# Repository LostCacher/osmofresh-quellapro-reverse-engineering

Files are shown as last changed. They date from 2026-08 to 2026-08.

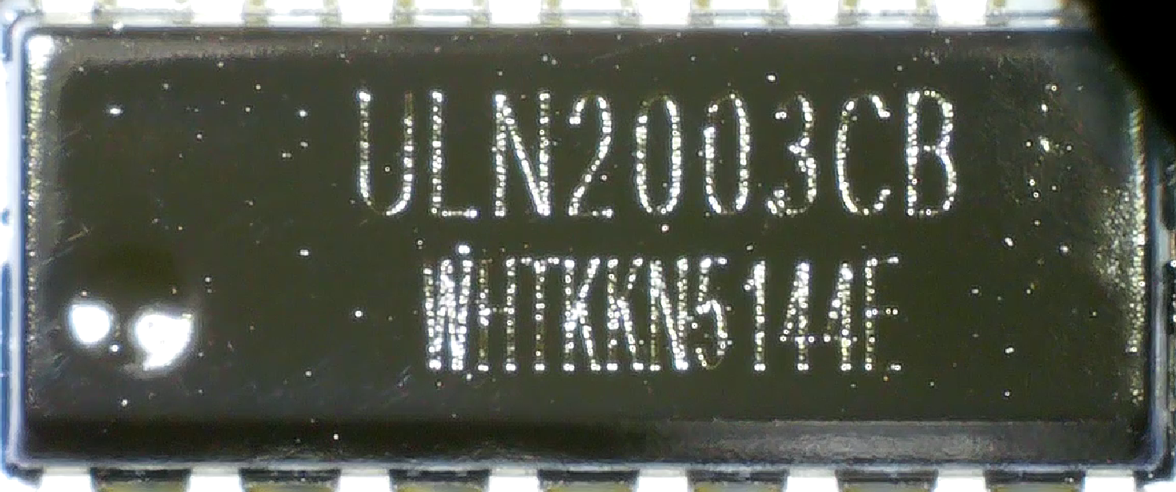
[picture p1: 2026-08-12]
Pictures/Display_U1.png

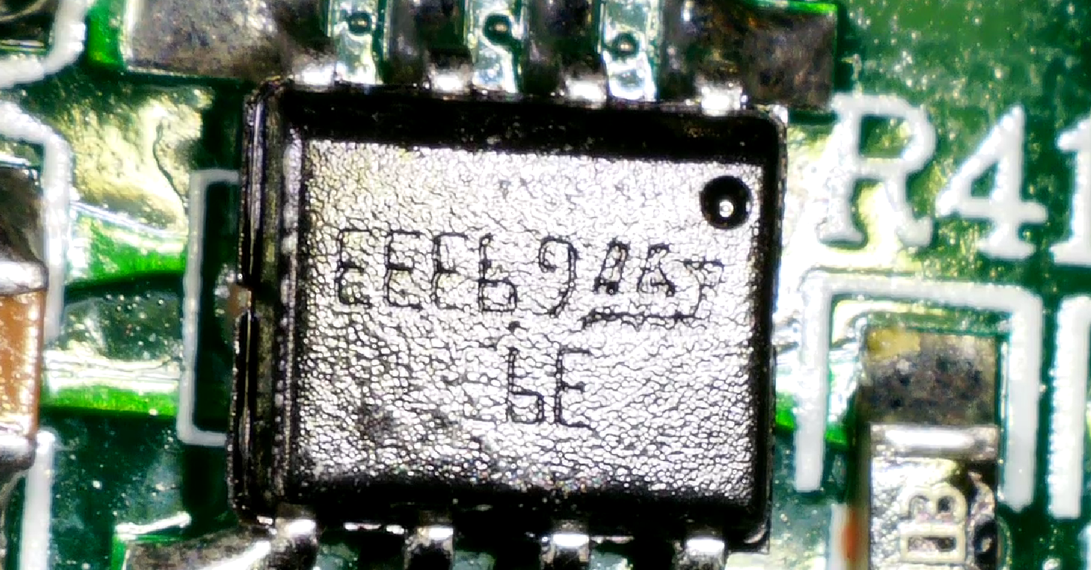
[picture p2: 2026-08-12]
Pictures/Hauptplatine_U5_8Pin.png

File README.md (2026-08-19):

# OsmoFresh Quella Pro Reverse Engineering

> Reverse engineering and hardware documentation of the OsmoFresh Quella Pro water dispenser.

## Project Goals

This project aims to document the hardware architecture of the OsmoFresh Quella Pro to improve repairability and technical understanding.

Current objectives include:

- Reverse engineering the hardware
- Creating complete schematics
- Identifying electronic components
- Documenting the UART communication protocol
- Documenting sensors and actuators
- Exploring the possibility of custom firmware (if technically feasible)

## Repository Structure

```
Hardware/
Documentation/
Photos/
Datasheets/
Measurements/
UART/
Firmware/
```

## Project Status

⚠️ This project is currently work in progress.
The published schematics are based on reverse engineering and may contain errors or incomplete sections.

- ✅ Device teardown
- ✅ Component identification
- ✅ Primary power stage schematic
- ✅ Main PCB reverse engineering
- 🔄 UART protocol analysis
- ⏳ Firmware investigation

## Contributions, corrections and additional information are welcome.

## Disclaimer

This repository contains independently created documentation based on reverse engineering.

No proprietary firmware, copyrighted schematics, confidential documentation, or other copyrighted material from the manufacturer is included.

All schematics, measurements, photographs, and documentation were created independently.

## License

This repository is licensed under the MIT License.

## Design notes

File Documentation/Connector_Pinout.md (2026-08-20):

# Connector Pinout

## Primary Side (230 VAC)

| Connector | Description |
|---|---|
| **P1** | ACL → Heater |
| **P2** | ACN → Thermal safety switch → Heater |
| **P3** | ACN → AC mains input |
| **P4** | ACN → 24 VDC power supply |
| **P5** | ACL → 24 VDC power supply |
| **P6** | ACL → AC mains input |

---

## Secondary Side (24 VDC)

| Connector | Description |
|---|---|
| **CN1** | 24 VDC input (from power supply) [+24Vdc] |
| **CN2** | Reed switch (2-pin) – Water tank empty detection |
| **CN3** | Water temperature sensor (heater outlet) [+5Vdc] |
| **CN5** | Water temperature sensor (heater inlet) [+5Vdc] |
| **CN6** | Reed switch (2-pin) – Internal tank level sensor (black HW or NW) |
| **CN7** | UNUSED |
| **CN8** | UNUSED [+5Vdc] |
| **CN9** | TDS sensor (2-pin) |
| **CN10** | 6-pin actuator connector |
| **CN11** | Display interface (5 V, TX, RX, GND) [+5Vdc] |
| **CN12** | Feed Pump [+24Vdc] |
| **CN13** | UNUSED [+24Vdc] |
| **CN14** | Reed switch (2-pin) – Internal tank level sensor (red HW or NW)|
| **CN16** | UNUSED [+5Vdc] |

### CN10 Pinout

| Pin | Function |
|----:|---|
| 1 | GND |
| 2 | +24 V (Not connected) [+24Vdc] |
| 3 | GND |
| 4 | +24 V Flush Valve [+24Vdc] |
| 5 | GND |
| 6 | +24 V Booster Pump [+24Vdc] |

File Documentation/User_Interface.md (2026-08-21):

# User Interface

## Temperature Selection

| Option | Description |
|---|---|
| RT | Room Temperature Water |
| 45 °C | Milk |
| 55 °C | Tea |
| 80 °C | Soup |
| 90 °C | Coffee |
| 100 °C | Boiling Water |

---

## Volume Selection

| Volume |
|---------|
| 150 mL |
| 300 mL |
| 450 mL |
| 600 mL |
| 750 mL |
| 900 mL |

---

## User Controls

- Temperature Selection
- Volume Selection
- Filter Change
- Power On / Off
- Child Lock

---

## Status Indicators

- Selected Volume
- TDS Value
- Water Temperature
- Water Tank Empty (Red Water Drop)
- Filter Process Active (White Water Drop)
- Internal Tank Empty (White Water Drop Flashing)
- Filter Lifetime (Stage 1 / 2 / 3)
- Malfunction + Error Code

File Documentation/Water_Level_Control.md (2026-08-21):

# Water Level Control

This document describes the water level monitoring and pump control logic of the internal and external water tanks.

---

# Sensors

## Internal Tank Level MIN

- Connector: CN14
- Reed switch: Normally Closed (NC)
- Trigger height: ~90 mm
- Function:
  - Indicates that the minimum required water level has been reached.
  - Enables the feed pump.
  - Does **not** start the feed pump automatically.

---

## Internal Tank Level MAX

- Connector: CN6
- Reed switch: Normally Closed (NC)
- Trigger height: ~180 mm
- Function:
  - Stops / inhibits the booster pump.

---

## External Water Tank Empty

- Connector: CN2
- Reed switch: Normally Open (NO)
- Function:
  - Detects an empty external water tank.
  - Stops / inhibits the booster pump.

---

# Booster Pump Logic

The booster pump is inhibited when:

- The external water tank is empty.
- The internal tank reaches the MAX level.

The booster pump is allowed to operate again when the corresponding inhibit condition is no longer present.

---

# Feed Pump Logic

The feed pump may only operate when:

- The Internal Tank Level MIN sensor has been reached (feed pump enabled).

The MIN sensor only provides the permission to operate the feed pump.
The feed pump starts only when requested by the control logic (e.g. during a dispensing cycle).

---

# Dispensing Logic

The controller keeps track of the **cumulative dispensing time**.

After approximately **25 seconds of total water dispensing**, the booster pump is enabled again to refill the internal tank.

The dispensing time is accumulated across multiple dispensing cycles and is not reset when dispensing is interrupted.

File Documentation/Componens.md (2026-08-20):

# MainPCB Bill of Materials (BOM)

This document lists all components identified on the OsmoFresh Quella Pro MainPCB.

> **Status**
> - ✅ = Identified
> - 🟡 = Partially identified
> - ❓ = Unknown / To be analyzed

---

# Protection Devices

| RefDes | Component | Value | Model | Status |
|---|---|---|---|:---:|
| FUSE1 | Fuse | T16A | TT16AL250V | ✅ |
| ZNR1 | Varistor | 560 V | VDR 14D561K | ✅ |

---

# Integrated Circuits (IC)

| RefDes | Component | Value / Function | Part Number / Marking | Package | Status | Notes |
|---|---|---|---|---|:---:|---|
| IC1 | MCU | Main Controller | HIGHWAY-C225F | QFP-28 | ✅ | Custom MCU |
| U1 | Buck Converter | 24 V → 5 V DC/DC | Unknown | SOT-23-5 | 🟡 | Step-down converter |
| U3 | Zero-Cross Triac Driver Optocoupler | MOC3063M | SOIC-6 | ✅ | Optically isolated zero-cross triac driver |
| U4 | Darlington Driver | 7-Channel Driver | ULN2003A | SOIC-16 | ✅ | Low-side driver array |
| U5 | Dual Comparator | Voltage Comparator | KM393 | SOIC-8 | ✅ | Dual comparator |

---

# Relays

| RefDes | Function | Model | Coil Voltage | Contact Rating | Status |
|---|---|---|---|---|:---:|
| K1 | Heater Relay | Vuanze Y32F-SS-124HM | 24 VDC | 10 A / 250 VAC | ✅ |
| K2 | Bosoter Pump Relay | Vuanze Y32F-SS-124DM | 24 VDC | 5 A / 250 VAC | ✅ |

---

# Mechanical Components

| RefDes | Description | Status | Notes |
|---|---|:---:|---|
| SW1 | Thermal Safety Switch | ✅ | Heater protection |

---

# Transformers / Magnetics

| RefDes | Component | Model | Status | Notes |
|---|---|---|:---:|---|
| T1 | Signal Transformer | JB-TV/A2/2-E | ✅ | AC sensing / Zero-cross detection |
| L1 | Inductor | Unknown | 🟡 | Parallel to buck inductor L1 |

---

# Transistors / Power Switches

| RefDes | Type | Part Number | Package | Status | Notes |
|---|---|---|---|:---:|---|
| Q1 | TRIAC | BTA16-800CW | TO-220 | ✅ | 900 W heater triac |
| Q2 | NMOS | Unknown | SOT-23 | 🟡 | Heater relay low-side driver |
| Q3 | NPN BJT | Unknown | SOT-23 | 🟡 | Input inverter / signal conditioning |
| Q4 | PMOS | Unknown | SOT-23 | 🟡 | Feed Pump high-side switch |
| Q5 | NPN BJT | Unknown | SOT-23 | 🟡 | Booster pump relay low-side driver |
| Q6 | NPN BJT | Unknown | SOT-23 | 🟡 | Input inverter / signal conditioning |
| Q8 | NPN BJT | Unknown | SOT-23 | 🟡 | PMOS gate driver |

---

# Diodes

| RefDes | Type | Model | Status | Notes |
|---|---|---|:---:|---|
| D4 | Flyback Diode | Unknown | 🟡 | K1 relay coil suppression |
| D5 | Flyback Diode | Unknown | 🟡 | Booster pump inductive load suppression |
| D6 | Flyback Diode | Unknown | 🟡 | Feed Pump inductive load suppression |
| D7 | Flyback Diode | Unknown | 🟡 | K2 relay coil suppression |

---

# Resistors

| RefDes | Value | Type | Package | Status | Notes |
|---|---|---|---|:---:|---|
| RL1 | Unknown | Resistor | SMD 1206 | 🟡 | Parallel to L1 (buck converter) |
| R4 | 2 kΩ | Resistor | SMD 0805 | ✅ | |
| R5 | 2 kΩ | Resistor | SMD 0805 | ✅ | |
| R6 | 10 kΩ | Resistor | SMD 0805 | ✅ | |
| R7 | 180 Ω | Resistor | SMD 2010 | ✅ | Triac gate resistor |
| R10 | 2 kΩ | Resistor | SMD 0805 | ✅ | |
| R11 | 10 kΩ | Resistor | SMD 0805 | ✅ | |
| R12 | 2 kΩ | Resistor | SMD 0805 | ✅ | |
| R13 | 2 kΩ | Resistor | SMD 0805 | ✅ | |
| R14 | 1 kΩ | Resistor | SMD 0805 | ✅ | |
| R15 | 10 kΩ | Resistor | SMD 0805 | ✅ | |
| R16 | 2 kΩ | Resistor | SMD 0805 | ✅ | |
| R17 | 2 kΩ | Resistor | SMD 0805 | ✅ | |
| R18 | 4.7 kΩ | Resistor | SMD 0805 | ✅ | |
| R19 | 470 Ω | Resistor | SMD 0805 | ✅ | |
| R20 | 10 kΩ | Resistor | SMD 0805 | ✅ | |
| R21 | 1 kΩ | Resistor | SMD 0805 | ✅ | |
| R22 | 2 kΩ | Resistor | SMD 0805 | ✅ | |
| R23 | 47 kΩ | Resistor | SMD 0805 | ✅ | |
| R24 | 2 kΩ | Resistor | SMD 0805 | ✅ | |
| R25 | 1 kΩ | Resistor | SMD 0805 | ✅ | |
| R26 | 82 kΩ | Resistor | SMD 1206 | ✅ | AC sense resistor chain |
| R27 | 82 kΩ | Resistor | SMD 1206 | ✅ | AC sense resistor chain |
| R28 | 82 kΩ | Resistor | SMD 1206 | ✅ | AC sense resistor chain |
| R29 | 10 kΩ | Resistor | SMD 0805 | ✅ | |
| R30 | 10 kΩ | Resistor | SMD 0805 | ✅ | |
| R31 | 4.7 kΩ | Resistor | SMD 0805 | ✅ | |
| R32 | 510 Ω | Resistor | SMD 0805 | ✅ | |
| R33 | 10 kΩ | Resistor | SMD 0805 | ✅ | |
| R34 | 510 Ω | Resistor | SMD 0805 | ✅ | |
| R35 | 10 kΩ | Resistor | SMD 0805 | ✅ | |
| R36 | 10 kΩ | Resistor | SMD 0805 | ✅ | |
| R37 | 10 kΩ | Resistor | SMD 0805 | ✅ | |
| R38 | 10 kΩ | Resistor | SMD 0805 | ✅ | |
| R40 | 10 kΩ | Resistor | SMD 0805 | ✅ | |
| R41 | 10 kΩ | Resistor | SMD 0805 | ✅ | |
| R44 | 330 Ω | Resistor | SMD 0805 | ✅ | |
| R45 | 2 kΩ | Resistor | SMD 0805 | ✅ | |
| R49 | 220 Ω | Resistor | SMD 0805 | ✅ | |
| R50 | 220 Ω | Resistor | SMD 0805 | ✅ | |
| R51 | 750 Ω | Resistor | SMD 1206 | ✅ | |
| R52 | 750 Ω | Resistor | SMD 1206 | ✅ | |
| R53 | 10 kΩ | Resistor | SMD 0805 | ✅ | |
| R54 | 10 kΩ | Resistor | SMD 0805 | ✅ | |
| R55 | 5.1 Ω | Power resistor | SMD 2010 | ✅ | Feed pump current shunt |
| R59 | 470 Ω | Resistor | SMD 0805 | ✅ | |
| R60 | 10 kΩ | Resistor | SMD 0805 | ✅ | |
| R61 | 47 kΩ | Resistor | SMD 0805 | ✅ | |
| R62 | 0.62 Ω | Power resistor | Axial THT | ✅ | Booster pump current shunt |
| R63 | 0.62 Ω | Power resistor | Axial THT | ✅ | Booster pump current shunt |
| R64 | 2 kΩ | Resistor | SMD 0805 | ✅ | |
| R65 | 2 kΩ | Resistor | SMD 0805 | ✅ | |
| R66 | 2 kΩ | Resistor | SMD 0805 | ✅ | |
| R67 | 10 kΩ | Resistor | SMD 0805 | ✅ | |
| R68 | 10 kΩ | Resistor | SMD 0805 | ✅ | |

---

# Capacitors

| RefDes | Value | Type | Package | Voltage | Status | Notes |
|---|---|---|---|---|:---:|---|
| XC1 | 100 nF | X2 Safety Capacitor | Radial Box THT (10 mm LP) | 275 VAC | ✅ | |
| EC1 | 470 µF | Electrolytic | Radial Electrolytic Ø12.5 × 20 mm | 50 V | ✅ | |
| EC2 | 330 µF | Electrolytic | Radial Electrolytic Ø6.3 × 11 mm oder Ø6.3 × 11.5 mm | 10 V | ✅ | |
| C1 | Unknown | Ceramic | 0805 | Unknown | 🟡 | |
| C2 | Unknown | Ceramic | 0805 | Unknown | 🟡 | |
| C3 | Unknown | Ceramic | 0805 | Unknown | 🟡 | |
| C4 | Unknown | Ceramic | 0805 | Unknown | 🟡 | |
| C5 | Unknown | Ceramic | 0805 | Unknown | 🟡 | |
| C6 | Unknown | Ceramic | 0805 | Unknown | 🟡 | |
| C7 | Unknown | Ceramic | 0805 | Unknown | 🟡 | |
| C8 | Unknown | Ceramic | 0805 | Unknown | 🟡 | |
| C9 | Unknown | Ceramic | 0805 | Unknown | 🟡 | |
| C10 | Unknown | Ceramic | 0805 | Unknown | 🟡 | |
| C11 | Unknown | Ceramic | 0805 | Unknown | 🟡 | |
| C12 | Unknown | Ceramic | 0805 | Unknown | 🟡 | |
| C13 | Unknown | Ceramic | 0805 | Unknown | 🟡 | |
| C14 | Unknown | Ceramic | 0805 | Unknown | 🟡 | |
| C15 | Unknown | Ceramic | 0805 | Unknown | 🟡 | |
| C16 | Unknown | Ceramic | 0805 | Unknown | 🟡 | |
| C17 | Unknown | Ceramic | 0805 | Unknown | 🟡 | |
| C18 | Unknown | Ceramic | 0805 | Unknown | 🟡 | |
| C19 | Unknown | Ceramic | 0805 | Unknown | 🟡 | |
| C20 | Unknown | Ceramic | 0805 | Unknown | 🟡 | |
| C21 | Unknown | Ceramic | 0805 | Unknown | 🟡 | |
| C22 | Unknown | Ceramic | 0805 | Unknown | 🟡 | |
| C23 | Unknown | Ceramic | 0805 | Unknown | 🟡 | |
| C24 | Unknown | Ceramic | 0805 | Unknown | 🟡 | |
| C25 | Unknown | Ceramic | 0805 | Unknown | 🟡 | |
| C26 | Unknown | Ceramic | 0805 | Unknown | 🟡 | |
| C27 | Unknown | Ceramic | 0805 | Unknown | 🟡 | |

---

# Notes

- Unknown components will be updated as reverse engineering progresses.
- Values are taken from PCB markings whenever possible.
- Package sizes are identified by physical measurements where no manufacturer data is available.
- Datasheets are available in the `Datasheets/` directory where applicable.

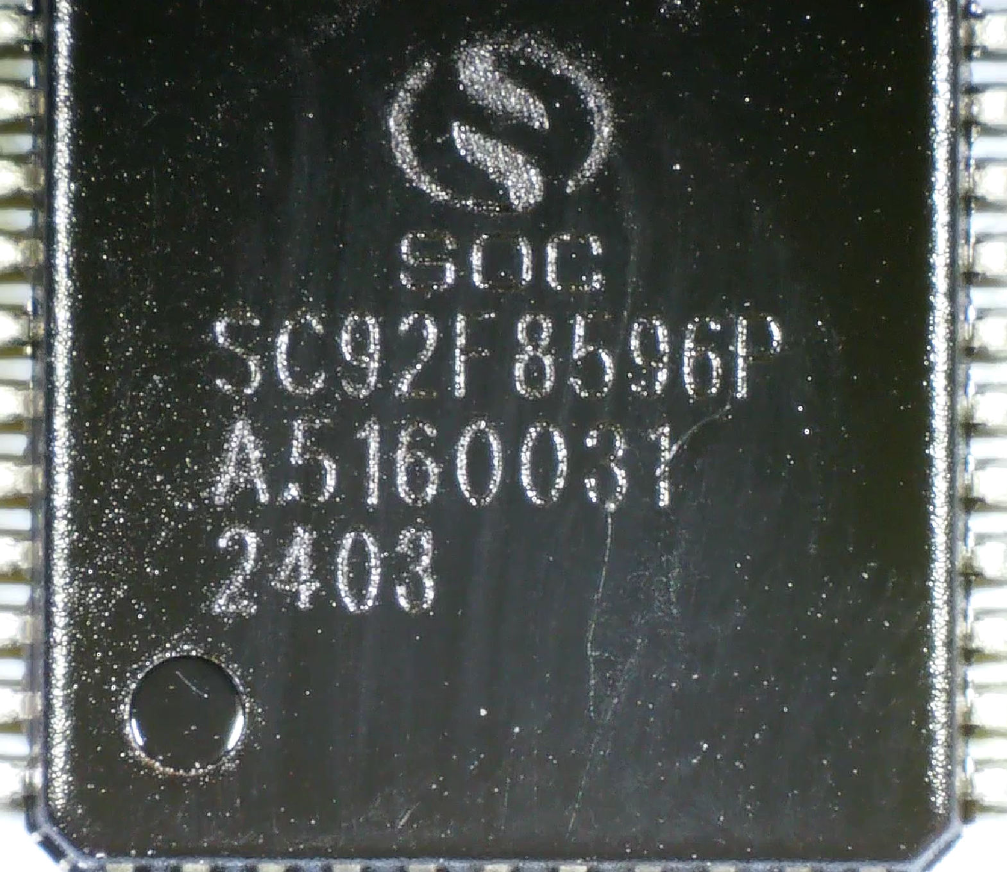
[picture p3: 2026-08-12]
Pictures/Display_U2.png

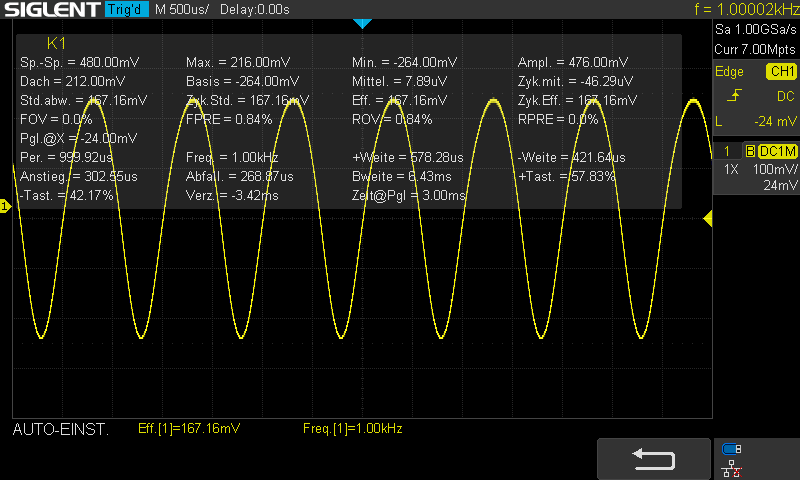
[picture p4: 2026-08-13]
Pictures/Transformer_Secondary.png

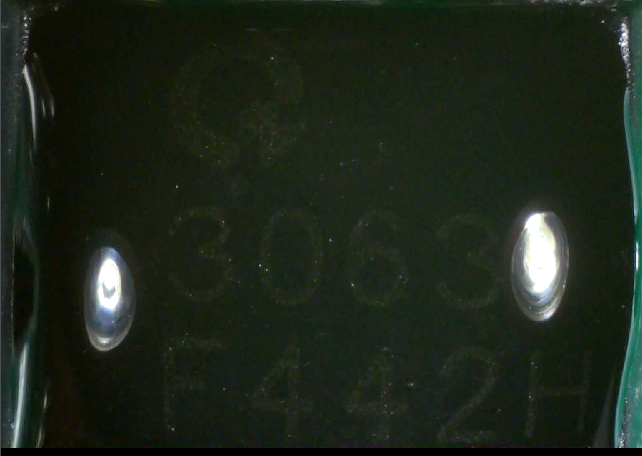
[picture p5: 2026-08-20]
Pictures/Hauptplatine_U3_6Pin.png

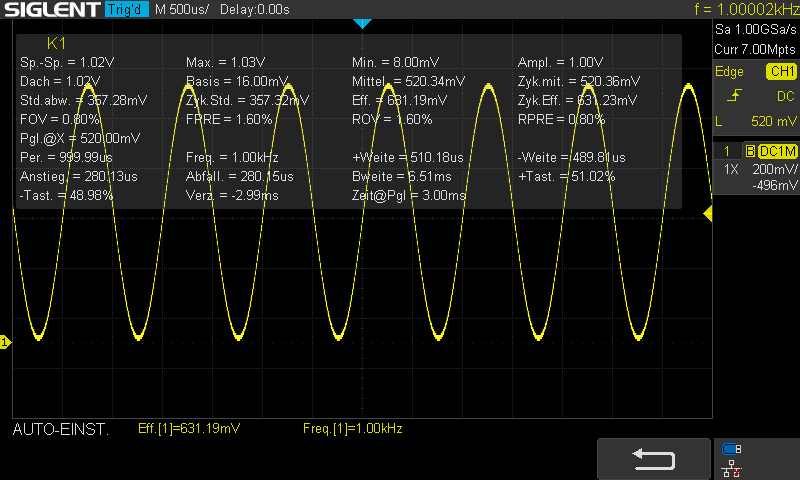
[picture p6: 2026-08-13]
Pictures/Transformer_Primary.png

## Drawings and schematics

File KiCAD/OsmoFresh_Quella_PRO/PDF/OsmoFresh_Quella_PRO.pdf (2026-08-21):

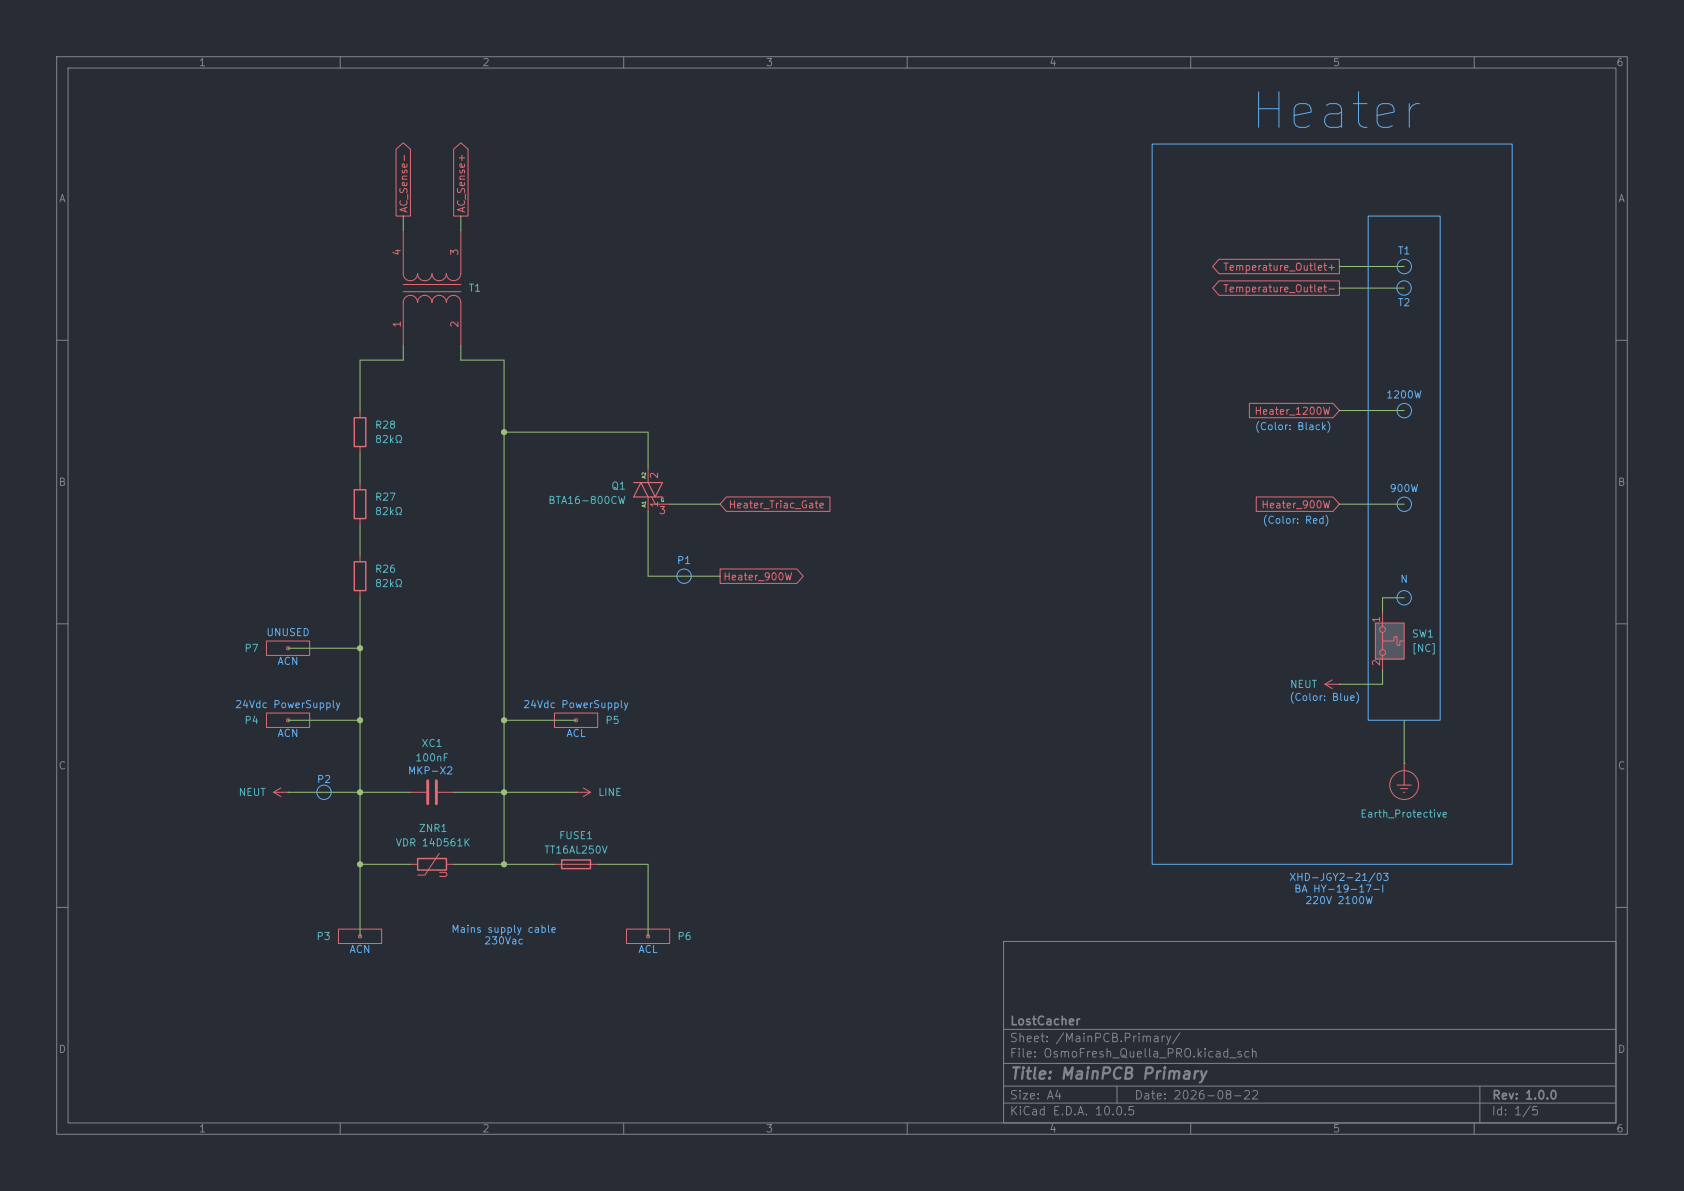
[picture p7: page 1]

P1 MKP-X2Mains supply cable 230Vac UNUSED

Size: A4 | Rev: 1.0.0
KiCad E.D.A. 10.0.5 | Id: 1/5

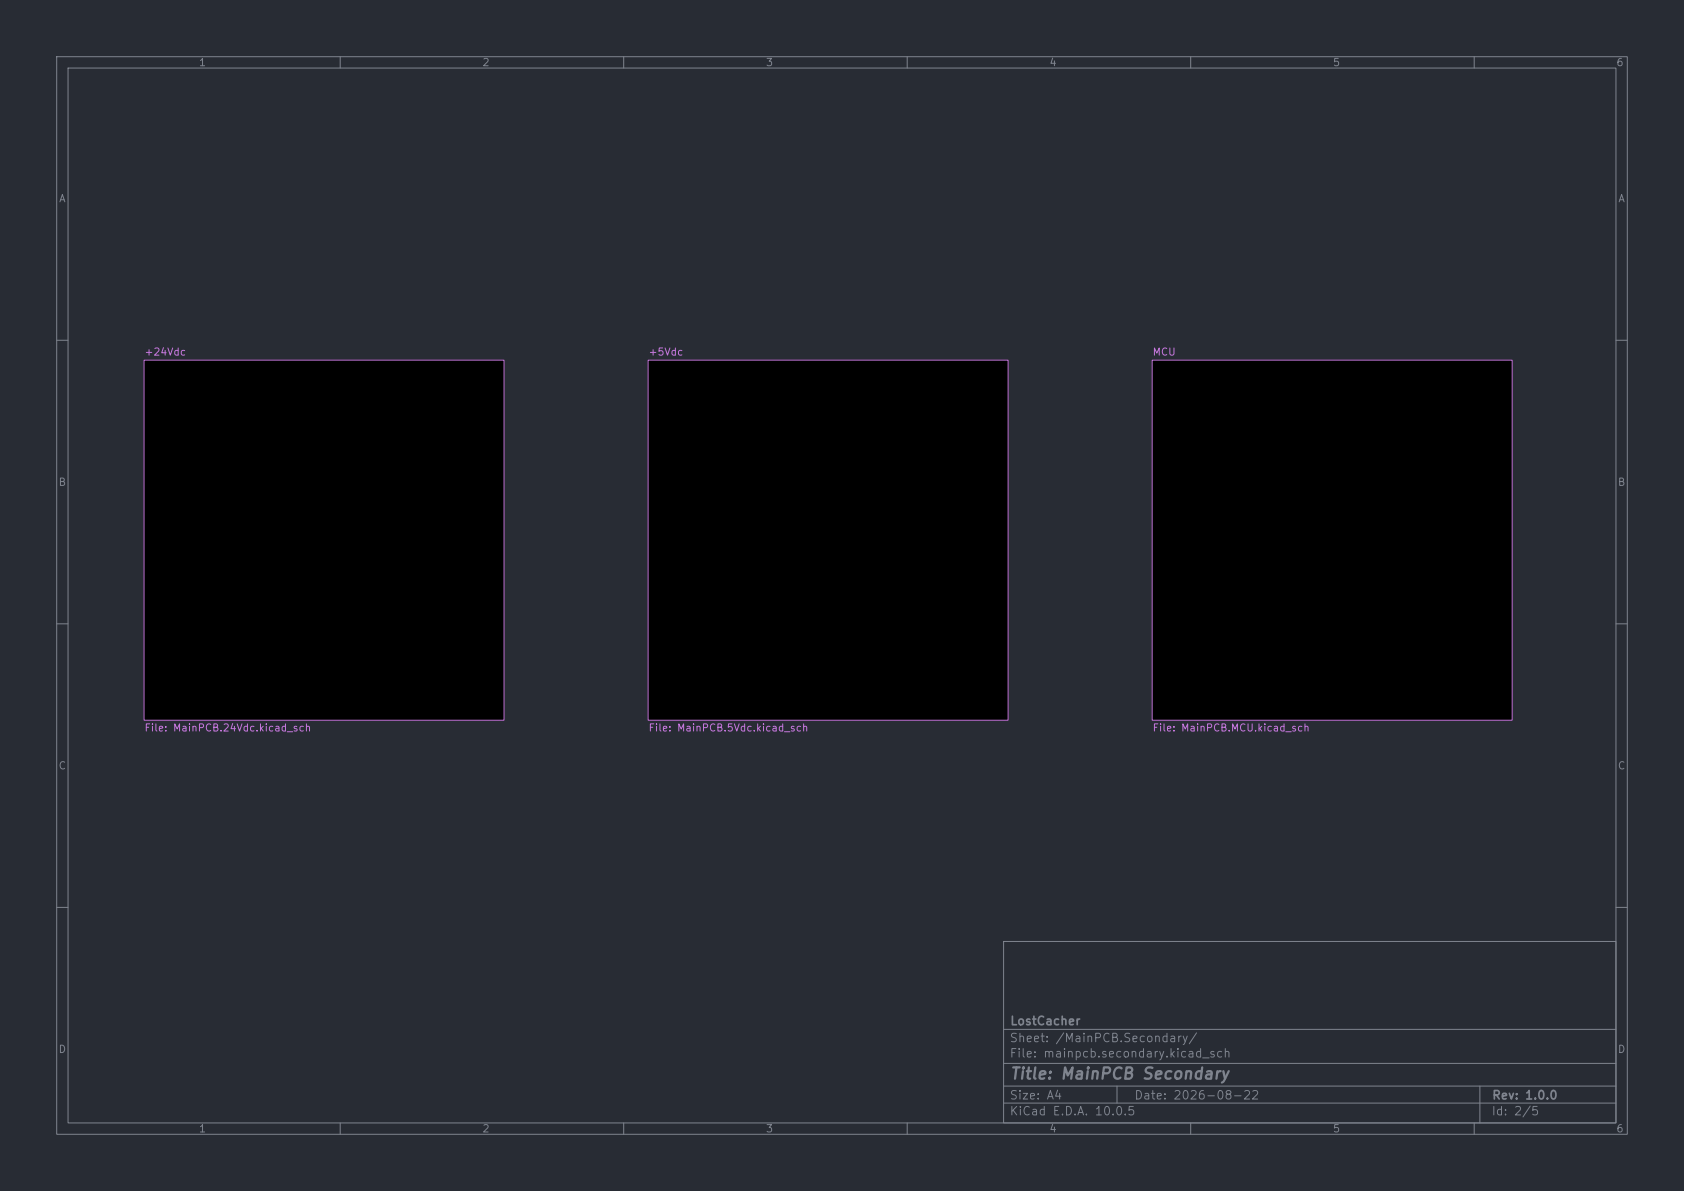
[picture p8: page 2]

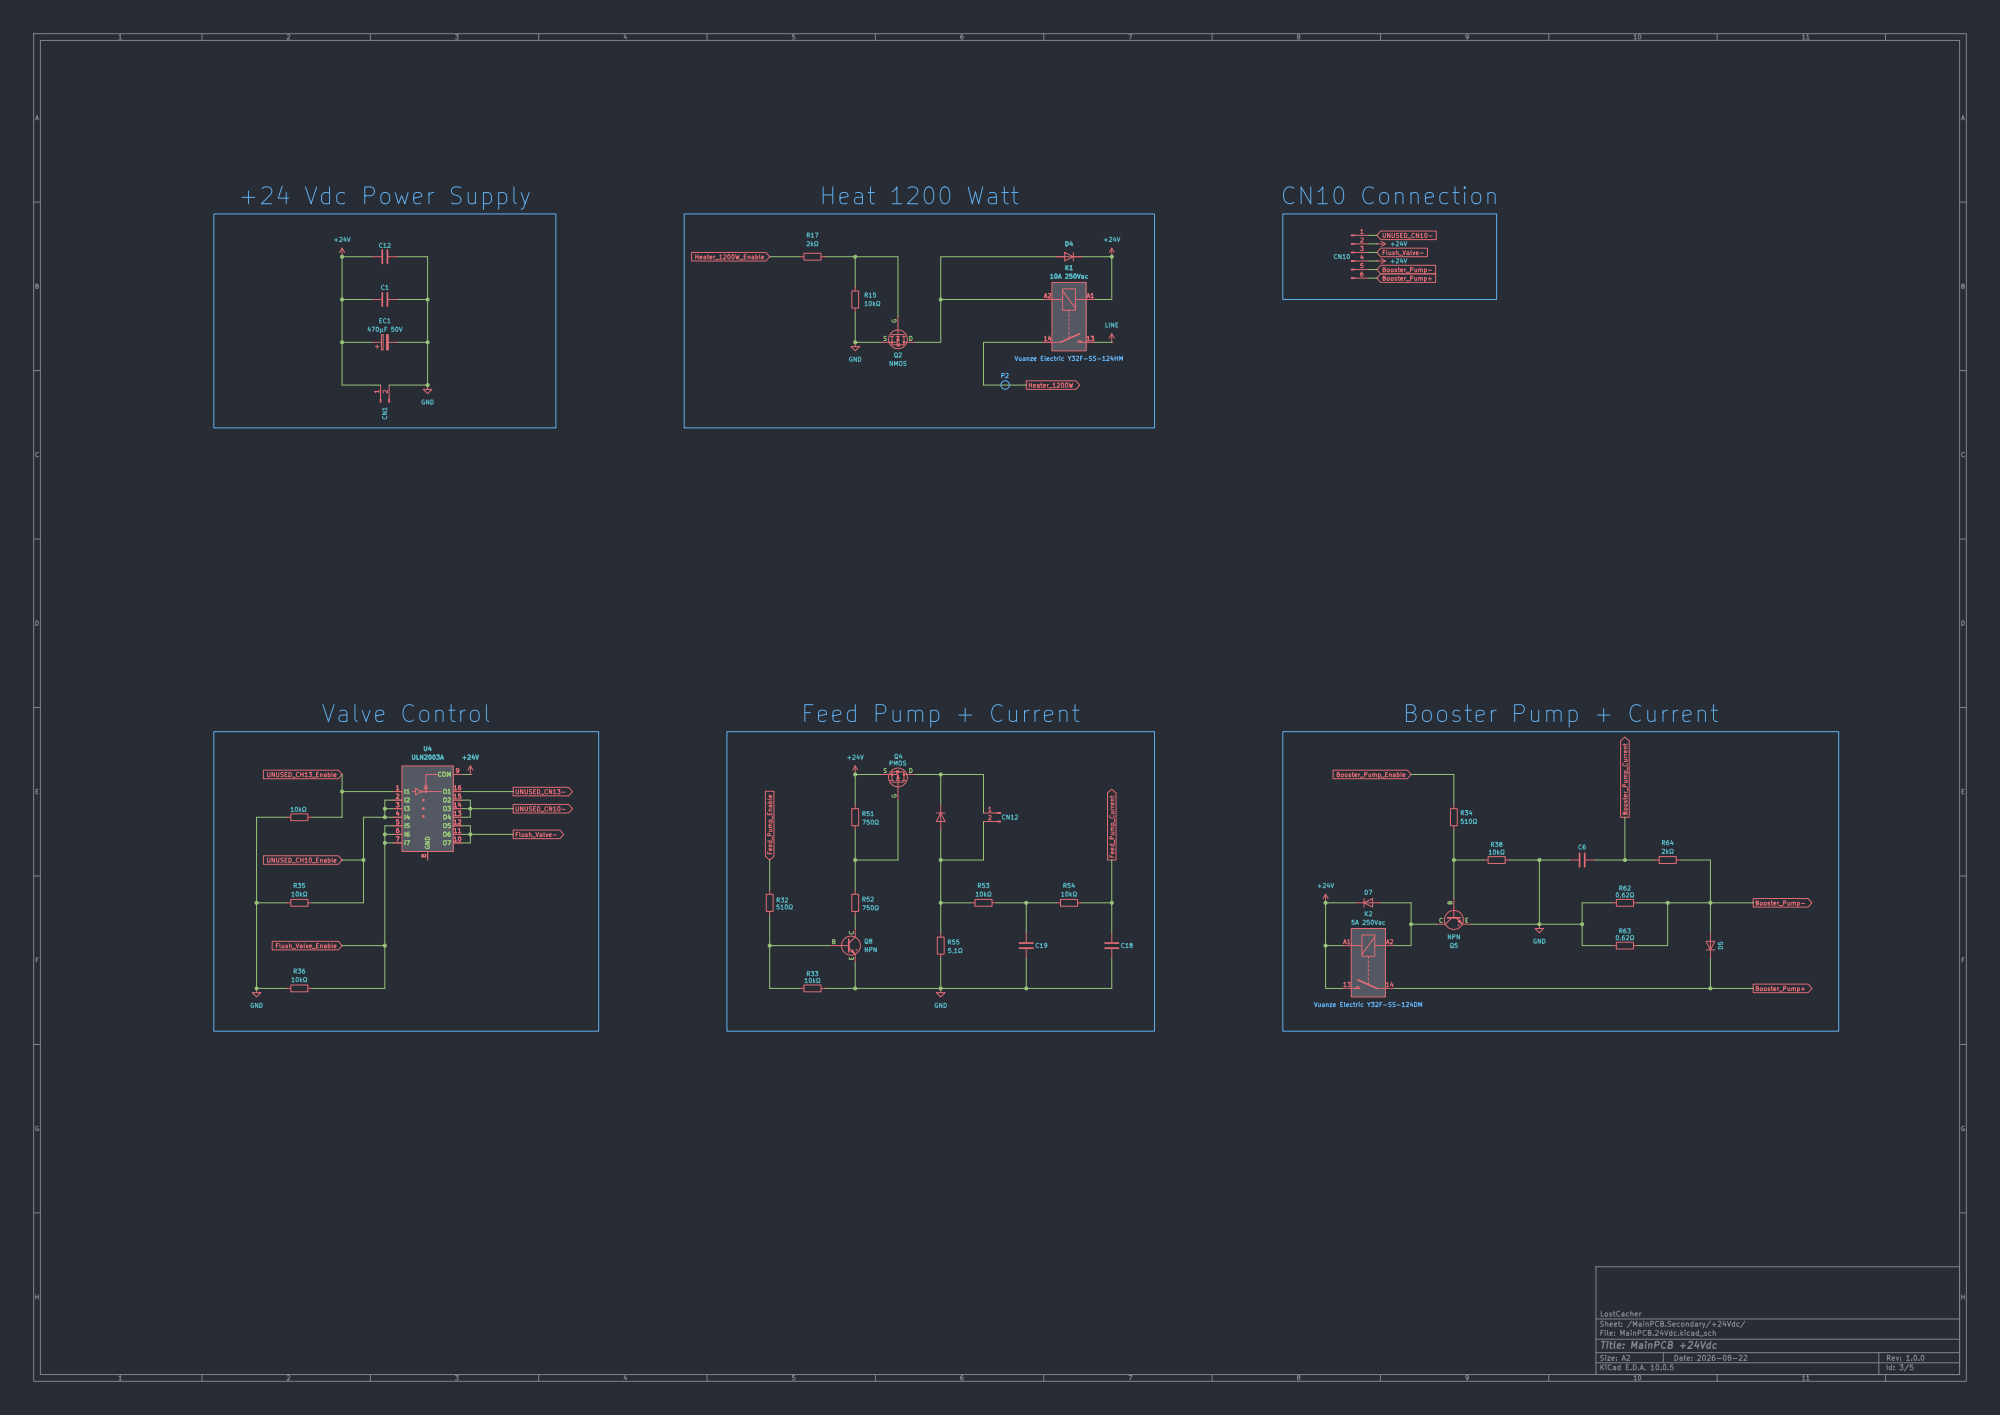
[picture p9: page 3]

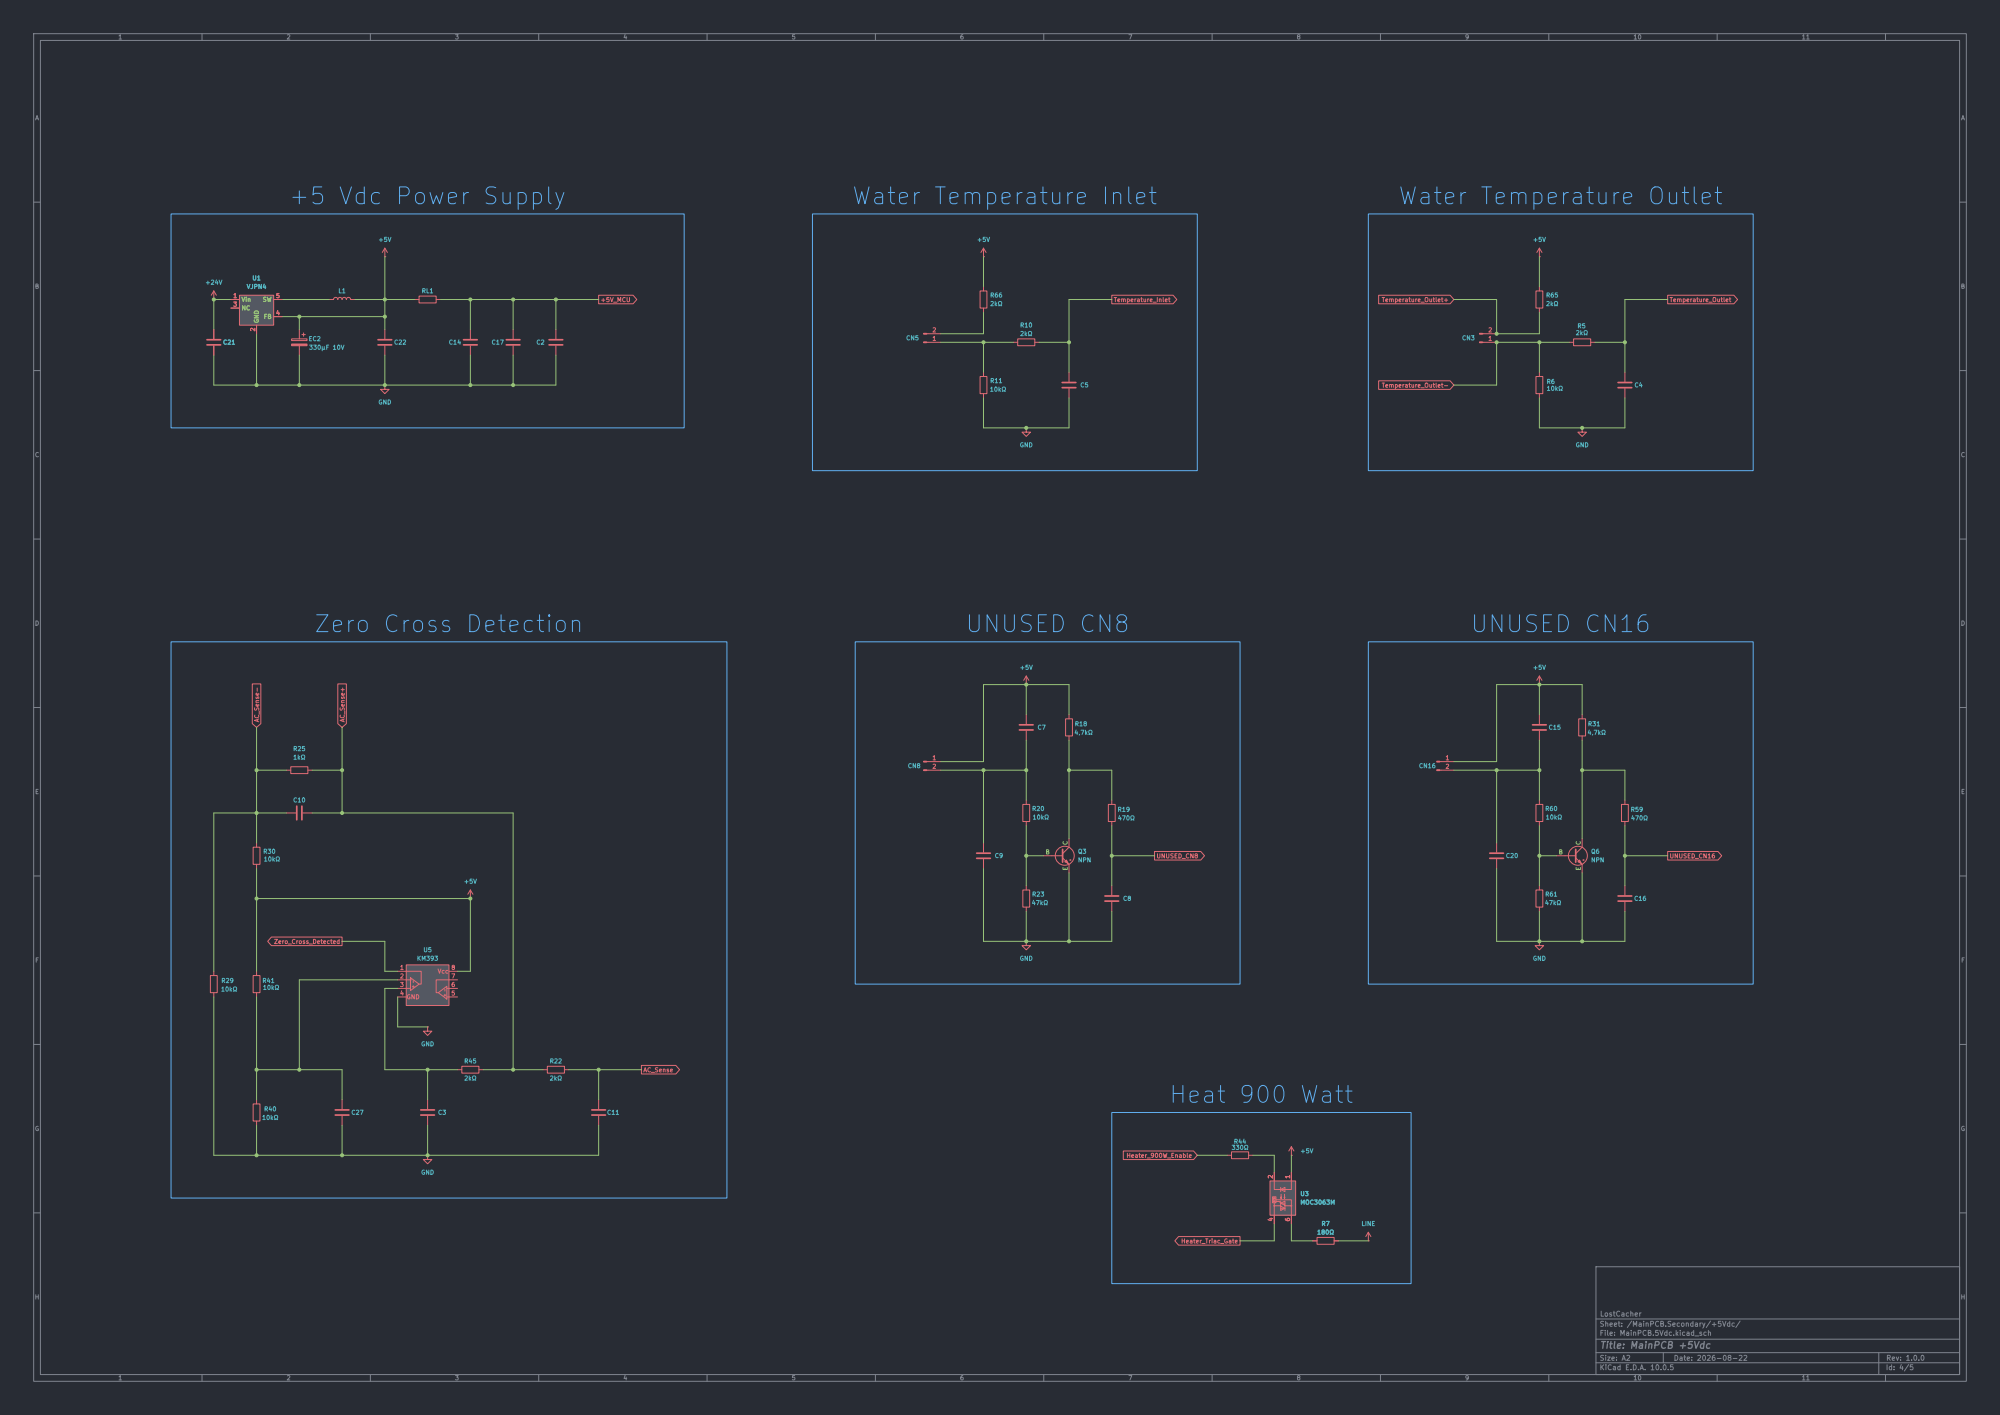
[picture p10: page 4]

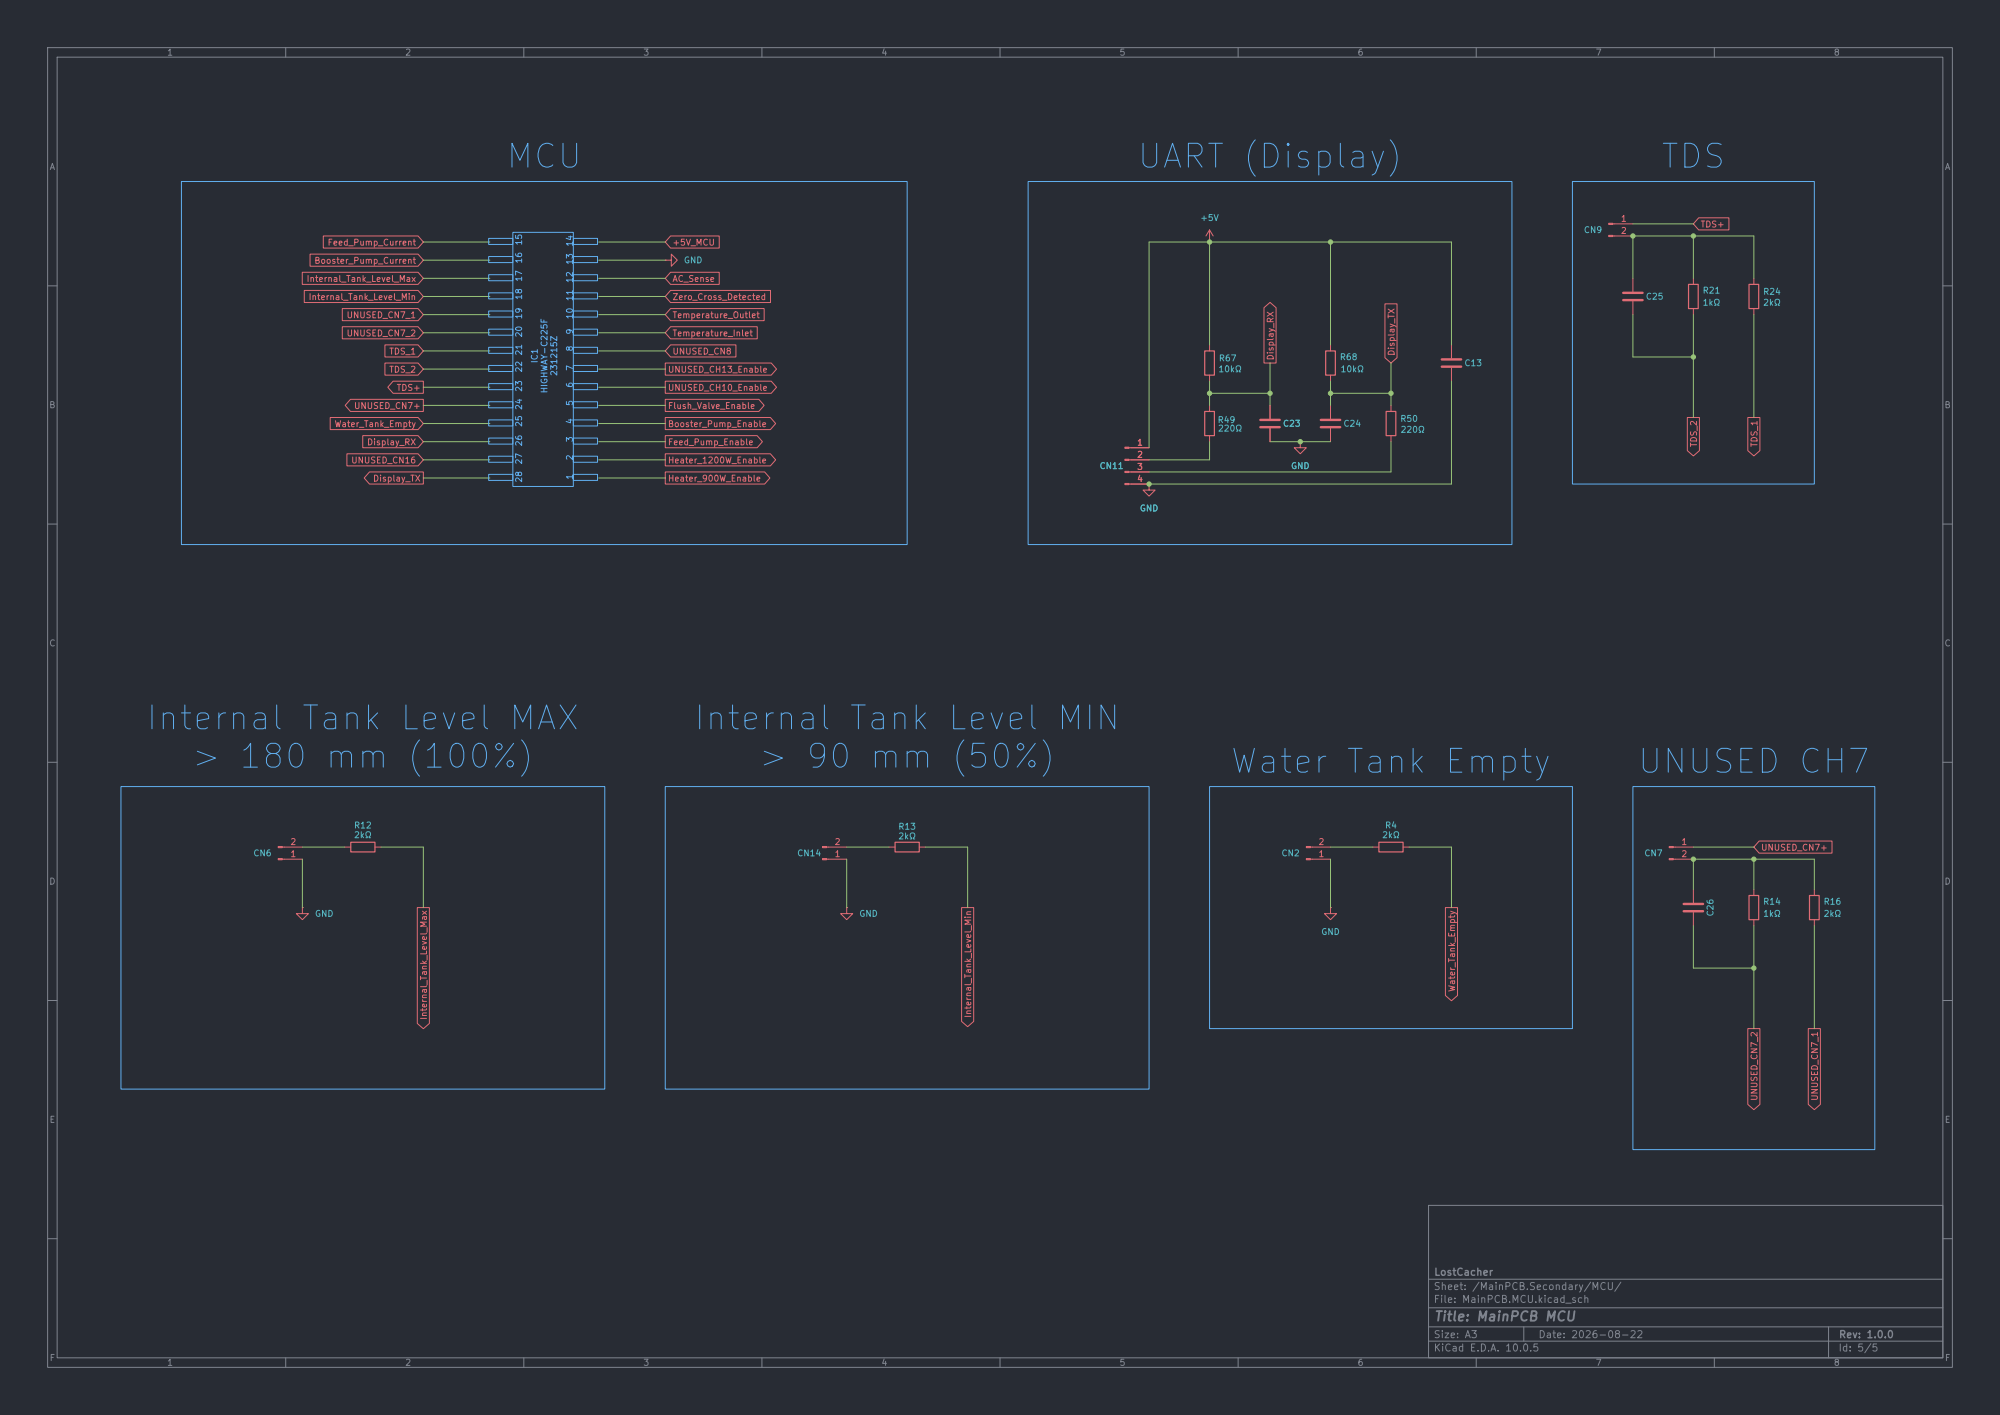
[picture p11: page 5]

5 Internal Tank Level MAX

Internal Tank Level MIN

LostCacher
Sheet: /MainPCB.Secondary/MCU/
File: MainPCB.MCU.kicad_sch
Title: MainPCB MCU

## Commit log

2026-08-12 Add initial reverse engineering files
    [OsmoFresh_Quella_PRO.kicad_pcb, OsmoFresh_Quella_PRO.kicad_sch, mainpcb.secondary.kicad_sch]
2026-08-12 Update Schematics
    [OsmoFresh_Quella_PRO.kicad_sch, connector.pinout.kicad_sch, mainpcb.connectors.kicad_sch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]
2026-08-12 Update Filestructure
    [mainpcb.secondary.kicad_sch]
2026-08-21 Update Documentation
    [MainPCB.MCU.kicad_sch]
2026-08-22 Update UART
